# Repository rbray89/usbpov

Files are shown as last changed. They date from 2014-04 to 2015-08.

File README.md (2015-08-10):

# usbpov

A small USB configurable POV toy

Some portions of this project are under the GNU General Public License (USB Device Driver Code for Atmel Devices) and should be distributed as-such. The licensing information can be found in /usbPOV-src/usbdrv

The remainder of the project is under the following license:

The MIT License (MIT)

Copyright (c) 2013-2014 Ryan Bray

Permission is hereby granted, free of charge, to any person obtaining a copy of this software and associated documentation files (the "Software"), to deal in the Software without restriction, including without limitation the rights to use, copy, modify, merge, publish, distribute, sublicense, and/or sell copies of the Software, and to permit persons to whom the Software is furnished to do so, subject to the following conditions:

The above copyright notice and this permission notice shall be included in all copies or substantial portions of the Software.

THE SOFTWARE IS PROVIDED "AS IS", WITHOUT WARRANTY OF ANY KIND, EXPRESS OR IMPLIED, INCLUDING BUT NOT LIMITED TO THE WARRANTIES OF MERCHANTABILITY, FITNESS FOR A PARTICULAR PURPOSE AND NONINFRINGEMENT. IN NO EVENT SHALL THE AUTHORS OR COPYRIGHT HOLDERS BE LIABLE FOR ANY CLAIM, DAMAGES OR OTHER LIABILITY, WHETHER IN AN ACTION OF CONTRACT, TORT OR OTHERWISE, ARISING FROM, OUT OF OR IN CONNECTION WITH THE SOFTWARE OR THE USE OR OTHER DEALINGS IN THE SOFTWARE.

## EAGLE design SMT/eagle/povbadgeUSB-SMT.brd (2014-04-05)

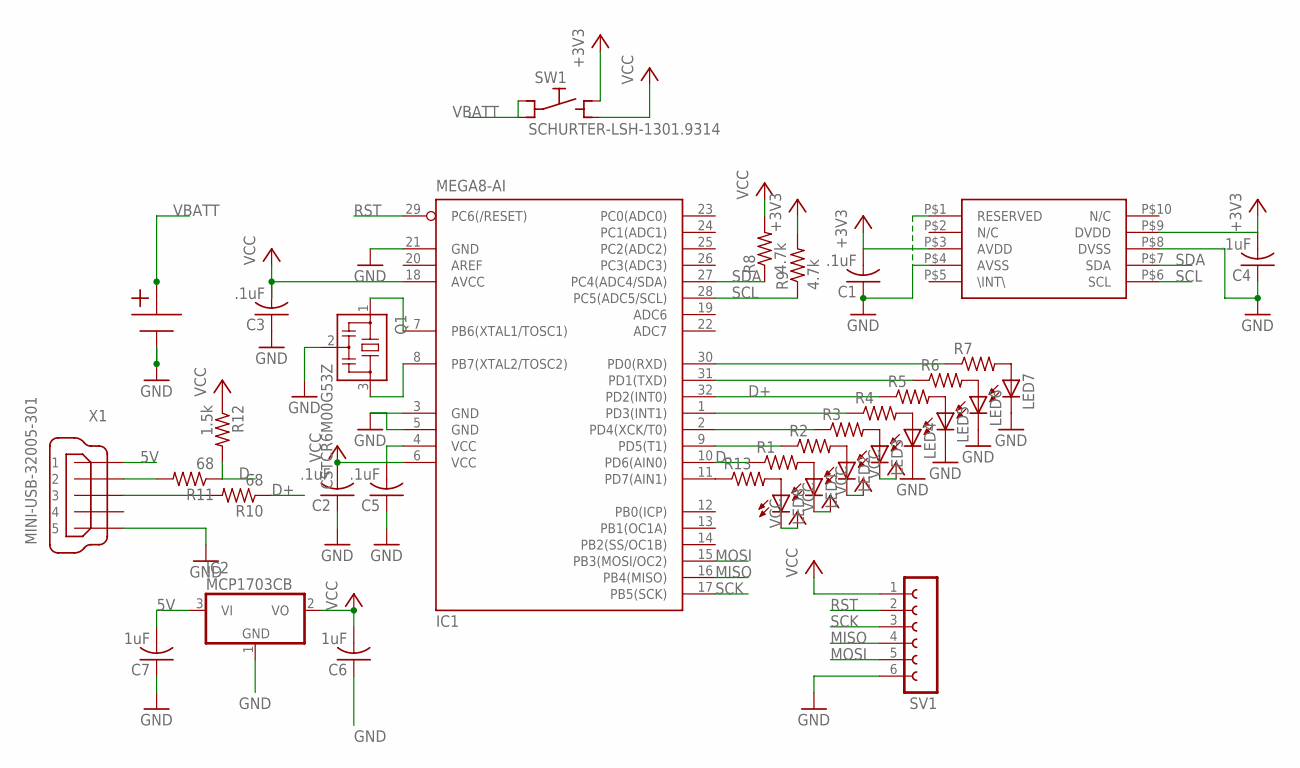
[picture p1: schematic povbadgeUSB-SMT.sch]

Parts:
C1, C2, C3, C4, C5: .1uF; C0805
C6, C7: 1uF; C0805
IC1: MEGA8-AI; TQFP32-08
IC2: MCP1703CB; SOT23
LED1, LED2, LED3, LED4, LED5, LED6, LED7, LED8: LEDCHIPLED_0805; CHIPLED_0805
MMA7660: MMA7660; DFN-10-HAND
Q1: CSTCR6M00G53Z; CSTCR6M
R1, R2, R3, R4, R5, R6, R7, R13: R-US_R0805; R0805
R8, R9: 4.7k; R0805
R10, R11: 68; R0805
R12: 1.5k; R0805
SV1: FE06W
SW1: SCHURTER-LSH-1301.9314; LSH
U$1: CR2032-CLIP; CR2032
X1: MINI-USB-32005-301; 32005-301

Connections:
5V: C7.2, IC2.3 (VI), X1.1
+3V3: C1.2, C4.2, MMA7660.P$3 (AVDD), MMA7660.P$9 (DVDD), R9.2, SW1.NO1 (NO)
D+: IC1.32 (PD2(INT0)), R5.1, R10.1
D-: IC1.10 (PD6(AIN0)), R1.1, R11.1, R12.2
GND: C1.1, C2.1, C3.1, C4.1, C5.1, C6.1, C7.1, IC1.3 (GND), IC1.5 (GND), IC1.21 (GND), IC2.1 (GND), LED4.C, LED5.C, LED6.C, LED7.C, MMA7660.P$1 (RESERVED), MMA7660.P$4 (AVSS), MMA7660.P$8 (DVSS), Q1.2, SV1.6, U$1.P$3, X1.5
INT1: IC1.1 (PD3(INT1)), R4.1
MISO: IC1.16 (PB4(MISO)), SV1.4
MOSI: IC1.15 (PB3(MOSI/OC2)), SV1.5
unnamed: LED1.A, R1.2
unnamed: IC1.11 (PD7(AIN1)), R13.1
unnamed: IC1.8 (PB7(XTAL2/TOSC2)), Q1.3
unnamed: IC1.7 (PB6(XTAL1/TOSC1)), Q1.1
unnamed: IC1.9 (PD5(T1)), R2.1
unnamed: LED8.A, R13.2
unnamed: LED2.A, R2.2
unnamed: LED3.A, R3.2
unnamed: LED4.A, R4.2
unnamed: LED5.A, R5.2
unnamed: LED6.A, R6.2
unnamed: LED7.A, R7.2
unnamed: R11.2, X1.2
unnamed: R10.2, X1.3
RST: IC1.29 (PC6(/RESET)), SV1.2
RXD: IC1.30 (PD0(RXD)), R7.1
SCK: IC1.17 (PB5(SCK)), SV1.3
SCL: IC1.28 (PC5(ADC5/SCL)), MMA7660.P$6 (SCL), R9.1
SDA: IC1.27 (PC4(ADC4/SDA)), MMA7660.P$7 (SDA), R8.1
TXD: IC1.31 (PD1(TXD)), R6.1
VBATT: SW1.C1 (C), SW1.C2 (C), U$1.P$1
VCC: C2.2, C3.2, C5.2, C6.2, IC1.4 (VCC), IC1.6 (VCC), IC1.18 (AVCC), IC2.2 (VO), LED1.C, LED2.C, LED3.C, LED8.C, R8.2, R12.1, SV1.1, SW1.NO2 (NO)
XCK: IC1.2 (PD4(XCK/T0)), R3.1

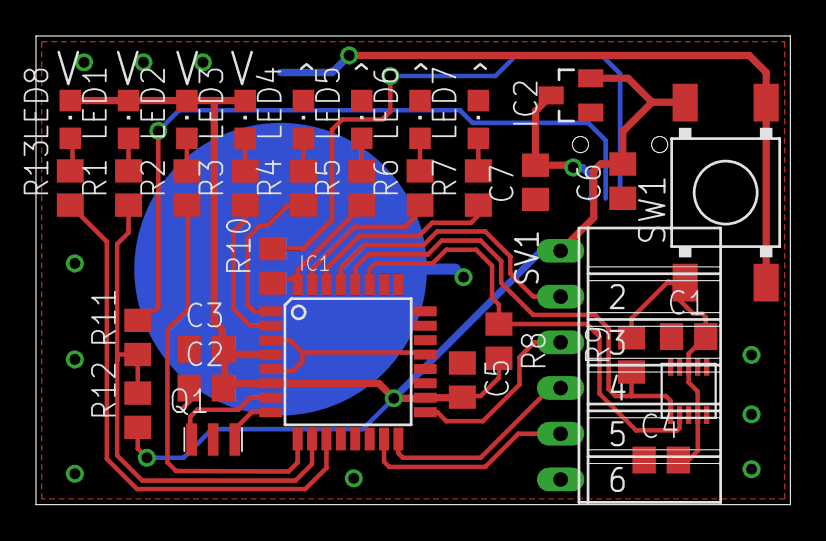
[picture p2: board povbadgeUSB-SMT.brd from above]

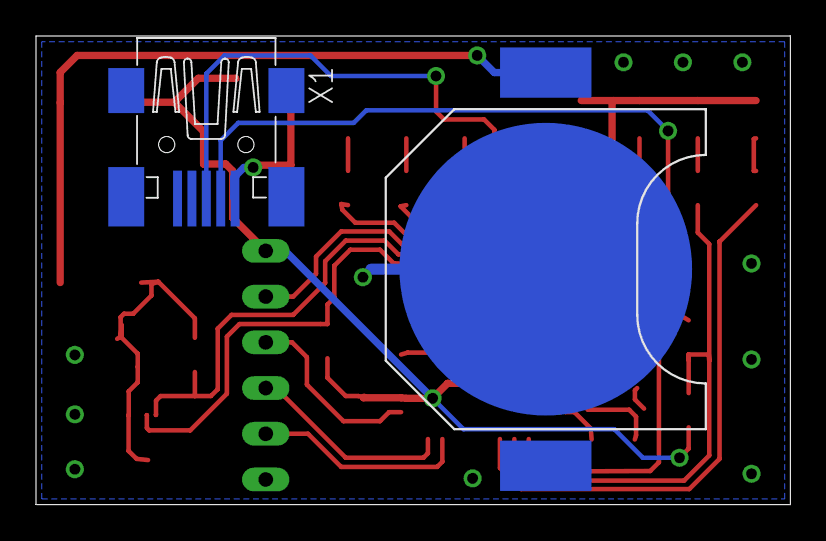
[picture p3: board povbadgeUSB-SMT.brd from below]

Board: 2 copper layers, 41.9 x 26.0 mm, 36 parts (2 on the bottom side), 31 nets.

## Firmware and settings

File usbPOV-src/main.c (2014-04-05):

#include <avr/io.h>
#include <util/delay.h>
#include <avr/pgmspace.h>
#include <avr/interrupt.h> 
#include <avr/eeprom.h>
#include <avr/wdt.h>

#include "usbconfig.h"
#include "usbdrv/usbdrv.h"
#include "usb.h"
#include "mma7660.h"

//defines the Port that is used for the LEDs.
#define LED_PORT PORTD
#define LED_DDR  DDRD


//Space equals 32!!!
//This defines a character array based off of dot matrix font.
// the PROGMEM attribute defines that the array is to go into program memory 
// and not SRAM. it has to be accessed in the following way though:
// pgm_read_byte(&(characterArray[x][y]))
unsigned char characterArray[96][6] PROGMEM = {
{0,	0,	0,	0,	0,	0},// 
{0,	0,	125,	0,	0,	0},// !
{0,	112,	0,	112,	0,	0},// "
{20,	127,	20,	127,	20,	0},// #
{18,	42,	127,	42,	36,	0},// $
{18,	42,	127,	42,	36,	0},// %
{54,	73,	85,	34,	5,	0},// &
{0,	0,	96,	0,	0,	0},// '
{0,	28,	34,	65,	0,	0},// (
{0,	65,	34,	28,	0,	0},// )
{20,	8,	62,	8,	20,	0},// *
{8,	8,	62,	8,	8,	0},// +
{0,	0,	5,	6,	0,	0},// ,
{0,	0,	5,	6,	0,	0},// -
{0,	0,	3,	3,	0,	0},// .
{2,	4,	8,	16,	32,	0},// /
{62,	69,	73,	81,	62,	0},// 0
{0,	33,	127,	1,	0,	0},// 1
{33,	67,	69,	73,	49,	0},// 2
{34,	65,	73,	73,	54,	0},// 3
{12,	20,	36,	127,	4,	0},// 4
{114,	81,	81,	81,	78,	0},// 5
{30,	41,	73,	73,	6,	0},// 6
{96,	71,	72,	80,	96,	0},// 7
{54,	73,	73,	73,	54,	0},// 8
{48,	73,	73,	74,	60,	0},// 9
{0,	0,	54,	54,	0,	0},// :
{0,	0,	53,	54,	0,	0},// ;
{8,	20,	34,	65,	0,	0},// <
{20,	20,	20,	20,	20,	0},// =
{0,	65,	34,	20,	8,	0},// >
{32,	64,	69,	72,	48,	0},// ?
{38,	73,	79,	65,	62,	0},// @
{63,	68,	68,	68,	63,	0},// A
{127,	73,	73,	73,	54,	0},// B
{62,	65,	65,	65,	34,	0},// C
{127,	65,	65,	65,	62,	0},// D
{127,	73,	73,	73,	65,	0},// E
{127,	72,	72,	72,	64,	0},// F
{62,	65,	65,	73,	47,	0},// G
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
{32,	16,	8,	4,	2,	0},// backslash  
{0,	65,	65,	127,	0,	0},// ]
{16,	32,	64,	32,	16,	0},// ^
{1,	1,	1,	1,	1,	0},// _
{0,	64,	32,	16,	0,	0},// `
{2,	21,	21,	21,	15,	0},// a
{127,	9,	17,	17,	14,	0},// b
{14,	17,	17,	17,	2,	0},// c
{14,	17,	17,	9,	127,	0},// d
{14,	21,	21,	21,	12,	0},// e
{8,	63,	72,	64,	32,	0},// f
{8,	21,	21,	21,	30,	0},// g
{127,	8,	16,	16,	15,	0},// h
{0,	9,	95,	1,	0,	0},// i
{0,	2,	1,	17,	94,	0},// j
{0,	127,	4,	10,	17,	0},// k
{0,	65,	127,	1,	0,	0},// l
{31,	16,	15,	16,	15,	0},// m
{31,	8,	16,	16,	15,	0},// n
{14,	17,	17,	17,	14,	0},// o
{31,	20,	20,	20,	8,	0},// p
{8,	20,	20,	12,	31,	0},// q
{31,	8,	16,	16,	8,	0},// r
{9,	21,	21,	21,	2,	0},// s
{16,	126,	17,	1,	2,	0},// t
{30,	1,	1,	2,	31,	0},// u
{28,	2,	1,	2,	28,	0},// v
{30,	1,	6,	1,	30,	0},// w
{17,	10,	4,	10,	17,	0},// x
{24,	5,	5,	5,	30,	0},// y
{17,	19,	21,	25,	17,	0},// z
{0,	8,	54,	65,	0,	0},// {
{0,	0,	127,	0,	0,	0},// |
{0,	65,	54,	8,	0,	0},// }
{4,	8,	8,	4,	8,	0},// ~
{4,	50,	2,	50,	4,	0}// SMILEY		95+32 = 0x7F
};

#define MAXPGMCHAR 96

volatile unsigned char eepromChars[8][6];
//*************  Hover Text Message  ***************
volatile unsigned char message[200];
volatile unsigned char msgLength;
volatile unsigned int  STRING_DELAY;	


volatile signed int characterPosition = 0;
volatile signed int linePosition = 0;
volatile char LEDToggle = 0;
volatile unsigned int delay = 0;
volatile char startFloat = 0;
volatile char direction = 0;

volatile unsigned int time = 0;
volatile unsigned char stringNumS = 0;
volatile unsigned char stringNumE = 0;


int main(void)
{

//USB 16 bit detection timer
TCCR1B |= ((1 << CS12));// | (1 << CS10)); // Set up timer at Fcpu/256 

	wdt_enable(WDTO_1S);
	
	usbHardwareInit();

	usbInit();
	sei();
TCNT1 = 0;
    for(;;){    // main event loop 
        wdt_reset();
        usbPoll();
//ticks = .3*12000000/256 = 23437
	if( !usbDetected && TCNT1 > 40437)
		break;
	}
//	cli();
	wdt_disable();
	EIMSK  &= ~(1<<INT0);

   TCCR1B |= ((1 << CS12));// | (1 << CS10)); // Set up timer at Fcpu/256 
   TCCR0B |= (1 << CS02) | (1 << CS00);// Set up timer at Fcpu/1024
   TCCR0A |= (1 << WGM01);//setup compare
//OCR0A - Compare Registers...
//OCR0B - Compare Registers...


//   sei(); //  Enable global interrupts 

// Set the PORTD (LEDs) as Output:
  LED_DDR= 0xFF;
    
  // Turn off LEDs
  LED_PORT = 0xF0;

	//Initialize the accelarometer.
MMA7660_Init();

//EEPROM Memory Format... 

//First Byte (adress 0) contains the message length.
//Second Byte to 200 contain the message.
//Remainder: to be determined.

//Fetch Message Length From EEPROM
msgLength = eeprom_read_byte((uint8_t*)0); 

//Fetch Message from EEPROM
eeprom_read_block((void*)&message, (const void*)1, 200); 

//Fetch delay time from EEPROM
STRING_DELAY = eeprom_read_word ((uint16_t*)201);
//STRING_DELAY = 2000;

//Add extra chars stored in EEPROM
eeprom_read_block((void*)&eepromChars, (const void*)203, 48); 



//Fix the Setup messsage end part...
	while(message[stringNumE] != '\n'){
		stringNumE++;
	}
	stringNumE--;


//Each timer tick = .000032s
//Each char therfore consists of approx. 318 ticks. = 6x1.7ms= 


char lock = 0;
char timeLock = 1;
char first = 1;
char left = 0;
//char right = 0;
char floatReady = 0;


unsigned int msgStart = 0;
unsigned int cycleCount = 0;
unsigned int start = 0;
unsigned int charDelay = 0;


TCNT1 = 0;
TCNT0 = 0;

  while(1){

	//get accelerometer values
	signed char accel = MMA7660_GetVal(YOUT);

	//find high accel
	if(accel <= -32 && !lock){

	lock = 1;
	timeLock = 0;
	//count a oscillation cycle
	cycleCount = TCNT1;
	TCNT1 = 0;
	//add offset to message as accel values are skewed slightly towards one direction of movement
	msgStart = cycleCount*3/11;


//make sure at least one cycle is recorded before message appears
	if(first == 2)
		first = 0;
	if(first == 1)
		first = 2;

	floatReady = 1;	
	left = 1;
	}
/*	else if(!first && accel >= 31 && !lock){

	lock = 1;
	timeLock = 0;
	
	msgStart = cycleCount/2 + cycleCount/6;

//	floatReady = 1;
//	right = 1;
	}
*/
	else if(first !=1 && lock && accel < 31 && accel > -32){
	lock = 0;
	
	}
	if(first < 1 && TCNT1 > msgStart && floatReady){
		floatReady = 0;
		if(left){
			left = 0;
			direction = 1;
		}
/*		else if(right){
			right = 0;
			direction = 0;
		}
*/

			startFloat = 1;
			//Calculate start time to float message...
			//1/4 of a cycle is half of a single wave, minus half the time to float the message... 
			//divied charDelay by an additional 4 to compensate for Timer0-1 prescale difference 
			charDelay = (cycleCount/16)/(stringNumE-stringNumS+1);	
			delay = charDelay/6;			
			start = charDelay/2;
			//reset message timer
			TCNT0 = 0;
			//Enable Output Compare A Interrupts on Timer0
			OCR0A = start;
			//enable interrupts on compare for Timer0
			TIMSK0 |= (1 << OCIE0A);

	}
	


  }

  return 0;
}

//Timer 0 interrupt service routine. 

//This is what grabs the value stored in SRAM for the image, and puts it up on to the LEDs, turns them off, then
//moves to the next row.
ISR(TIMER0_COMPA_vect)
{


time += OCR0A;

//beginning of message
if(startFloat == 1){
	startFloat = 2;
//reset position of chars
	if(direction == 1){
		characterPosition = stringNumS;
		linePosition = 0;
	}
/*	else{
		characterPosition = stringNumE;
		linePosition = 5;
	}
*/
//end of message
}else if(startFloat == 0){
//disable timer intterupt at end
	TIMSK0 &= ~(1 << OCIE0A);
//if next message break...
	if (time >= STRING_DELAY){
		time = 0;
//find next message basically, and set begining and end of string markers
		while(message[stringNumS] != '\n'){
			stringNumS++;
		}
		stringNumS++;
		if(stringNumS >= msgLength){
			stringNumS = 0;
			stringNumE = 0;
		}else{
			stringNumE += 2;
		}
			while(message[stringNumE] != '\n'){
				stringNumE++;
			}
			stringNumE--;
	}
}
//toggle the leds
if(!LEDToggle){
	unsigned char leds;
	LEDToggle = 1;
	unsigned char character = message[characterPosition]-' ';
	if(character >= MAXPGMCHAR)
	leds = eepromChars[character-MAXPGMCHAR][linePosition];
	else
	leds = (unsigned char)pgm_read_byte(&(characterArray[character][linePosition]));
//due to hardware, the top four leds need to be configured to be active LOW...
	leds = ((~leds)&0xF0)|(leds&0x0F);
	LED_PORT =  leds;
//reset timer
	OCR0A = delay/3;
	if(direction == 1){

//increment line position, if at end, goto next char, if past, reset float string to be done.
		linePosition++;
		if(linePosition == 6){
			linePosition = 0;
			characterPosition++;
		}
		if(characterPosition > stringNumE){
			startFloat = 0;
		}

	}
/*	else{
		
		linePosition--;
		if(linePosition == -1){
			linePosition = 5;
			characterPosition--;
		}
		if(characterPosition < stringNumS)
			startFloat = 0;

	}
*/
}
//turn leds off and reset timer.
else{
	LEDToggle = 0;
	LED_PORT =  0xF0;
	OCR0A = delay*2/3;

}


 
}

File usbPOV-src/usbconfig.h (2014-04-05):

/* Name: usbconfig.h
 * Project: V-USB, virtual USB port for Atmel's(r) AVR(r) microcontrollers
 * Author: Christian Starkjohann
 * Creation Date: 2005-04-01
 * Tabsize: 4
 * Copyright: (c) 2005 by OBJECTIVE DEVELOPMENT Software GmbH
 * License: GNU GPL v2 (see License.txt), GNU GPL v3 or proprietary (CommercialLicense.txt)
 * This Revision: $Id: usbconfig-prototype.h 785 2010-05-30 17:57:07Z cs $
 */

#ifndef __usbconfig_h_included__
#define __usbconfig_h_included__

/*
General Description:
This file is an example configuration (with inline documentation) for the USB
driver. It configures V-USB for USB D+ connected to Port D bit 2 (which is
also hardware interrupt 0 on many devices) and USB D- to Port D bit 4. You may
wire the lines to any other port, as long as D+ is also wired to INT0 (or any
other hardware interrupt, as long as it is the highest level interrupt, see
section at the end of this file).
*/

/* ---------------------------- Hardware Config ---------------------------- */

#define USB_CFG_IOPORTNAME      D
/* This is the port where the USB bus is connected. When you configure it to
 * "B", the registers PORTB, PINB and DDRB will be used.
 */
#define USB_CFG_DMINUS_BIT      6
/* This is the bit number in USB_CFG_IOPORT where the USB D- line is connected.
 * This may be any bit in the port.
 */
#define USB_CFG_DPLUS_BIT       2
/* This is the bit number in USB_CFG_IOPORT where the USB D+ line is connected.
 * This may be any bit in the port. Please note that D+ must also be connected
 * to interrupt pin INT0! [You can also use other interrupts, see section
 * "Optional MCU Description" below, or you can connect D- to the interrupt, as
 * it is required if you use the USB_COUNT_SOF feature. If you use D- for the
 * interrupt, the USB interrupt will also be triggered at Start-Of-Frame
 * markers every millisecond.]
 */
#define USB_CFG_CLOCK_KHZ       (F_CPU/1000)
/* Clock rate of the AVR in kHz. Legal values are 12000, 12800, 15000, 16000,
 * 16500, 18000 and 20000. The 12.8 MHz and 16.5 MHz versions of the code
 * require no crystal, they tolerate +/- 1% deviation from the nominal
 * frequency. All other rates require a precision of 2000 ppm and thus a
 * crystal!
 * Since F_CPU should be defined to your actual clock rate anyway, you should
 * not need to modify this setting.
 */
#define USB_CFG_CHECK_CRC       0
/* Define this to 1 if you want that the driver checks integrity of incoming
 * data packets (CRC checks). CRC checks cost quite a bit of code size and are
 * currently only available for 18 MHz crystal clock. You must choose
 * USB_CFG_CLOCK_KHZ = 18000 if you enable this option.
 */

/* ----------------------- Optional Hardware Config ------------------------ */

/* #define USB_CFG_PULLUP_IOPORTNAME   D */
/* If you connect the 1.5k pullup resistor from D- to a port pin instead of
 * V+, you can connect and disconnect the device from firmware by calling
 * the macros usbDeviceConnect() and usbDeviceDisconnect() (see usbdrv.h).
 * This constant defines the port on which the pullup resistor is connected.
 */
/* #define USB_CFG_PULLUP_BIT          4 */
/* This constant defines the bit number in USB_CFG_PULLUP_IOPORT (defined
 * above) where the 1.5k pullup resistor is connected. See description
 * above for details.
 */

/* --------------------------- Functional Range ---------------------------- */
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
